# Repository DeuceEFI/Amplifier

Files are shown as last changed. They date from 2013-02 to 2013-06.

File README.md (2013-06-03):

# ST Microelectronics TDA7293V Audio Amplifier

JAG 06/02/2013 2111 EDT (GMT-0400)

### Introduction

This is a high performance audio amplifier board based on the ST Microelectronics TDA7293V 100W Class AB audio amplifier IC.

Please see http://forum.diyefi.org/viewtopic.php?f=37&t=1966 for the most up to date information and links for this project.

### Goals

Core specs:

 * Uses TDA7293 integrated amp IC
 * Single board per chip/channel as small as reasonable with 2 layers without compromising noise performance
 * Simple interface to power and IO signals
 * Combine three together sharing a toroidal and main power filter caps for stereo bookshelfs + optional sub

Method:

 * Use reference schematics and layout as guides in order to minimise time to completion and effort required
 * Linkwitz Riley 24db/octave two way + merge electronic crossover to handle splitting signal for sub and bookshelfs
 * Internal star grounding scheme
 * Add some sophistication and quality by force to the circuit
 * Incorporate ground lift circuit to ensure ground-loop free operation
 * Utilise clip detection feature to drive LED on front panel per channel (20mA, make it obvious) 

Currently we are working on the schematics so no PCB file exists at this time.

### KiCAD modules

Copy the Amplifier.mod file to your KiCAD module directory, typically /usr/share/kicad/modules
 
### Status

This PCB is in active development, please refrain from printing circuit boards and expecting them to work.
This design is untested and should NOT be considered a usable design.

See TODO.md for the latest status of what needs to be done and what has already been done.

I will update this status as work progresses.

### Changes

Please send any changes that you make to the Amplifier back upstream to Andy Goss' copy at https://github.com/DeuceEFI/Amplifier

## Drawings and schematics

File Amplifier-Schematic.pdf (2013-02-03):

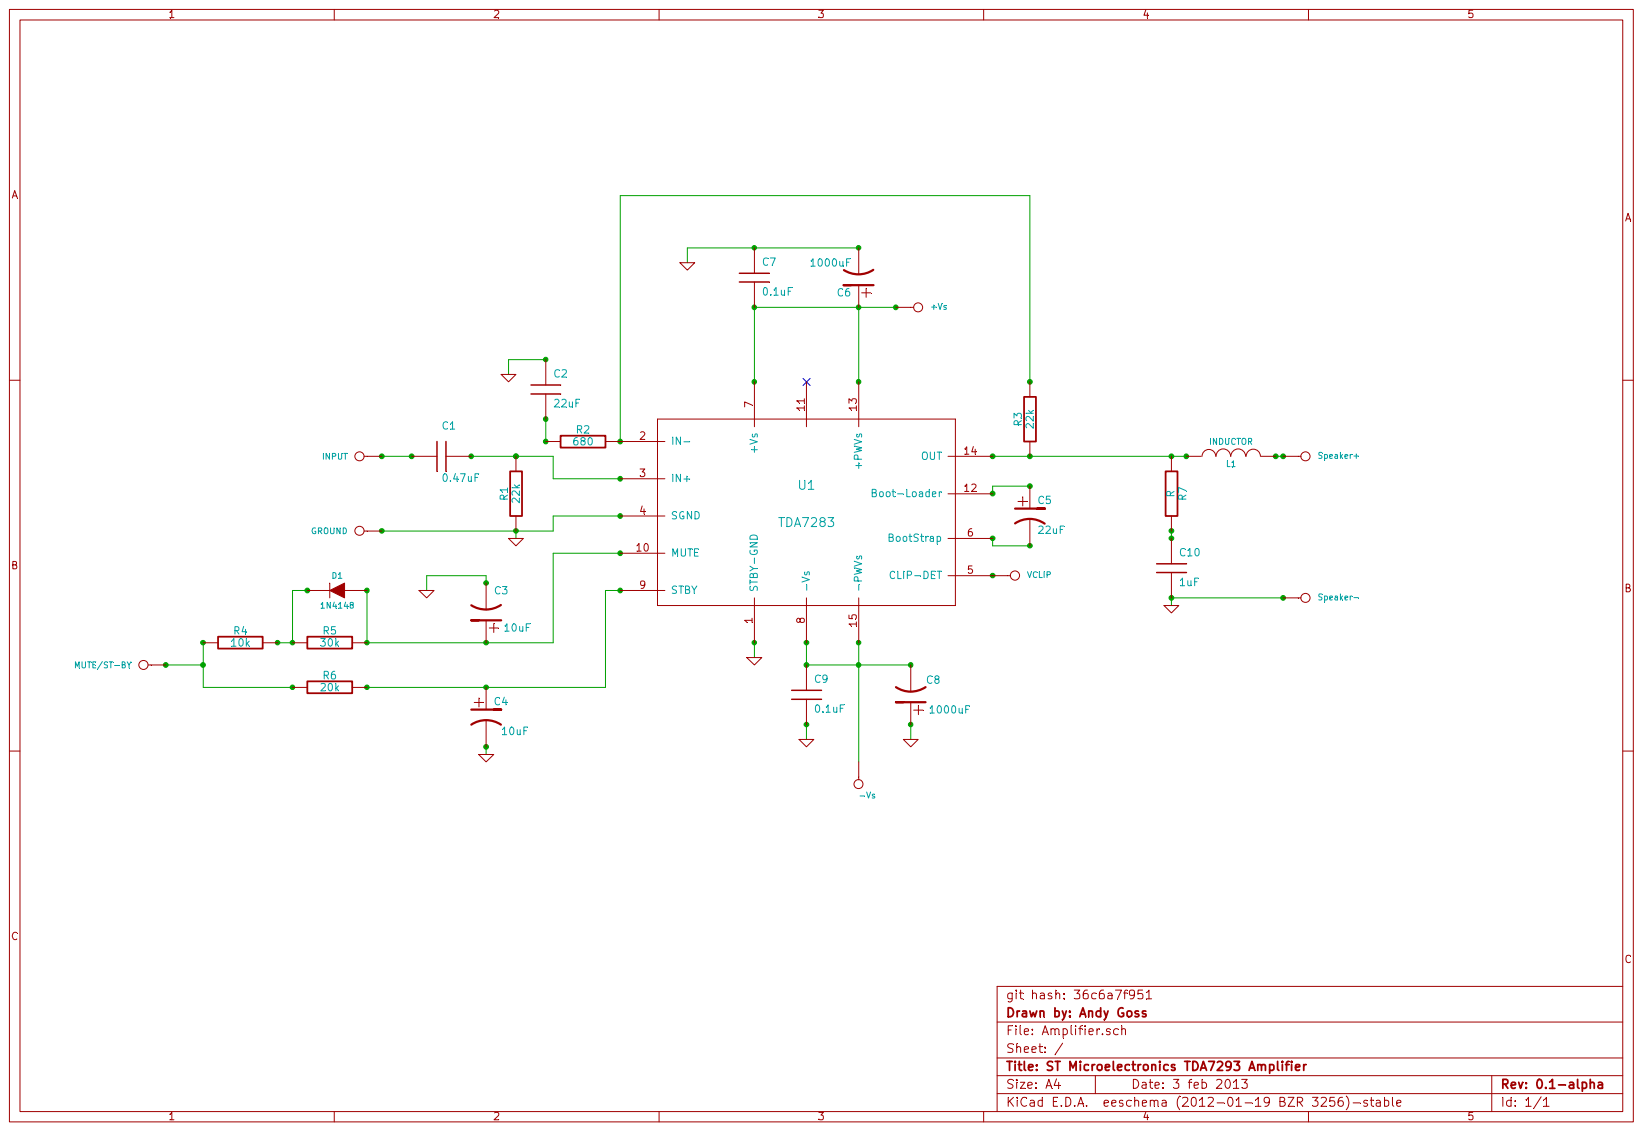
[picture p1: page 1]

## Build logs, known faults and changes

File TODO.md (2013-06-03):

# To Do List

## JAG 06/02/2013 2155 EDT (GMT-0400)

### Tasks to left to do:

* Move the input to the front of the board rather than the side. 
* Move the clip input to the front of the board rather than the side.
* Move the control line to the front of the board rather than the side.
* Move the Mute/Standby to the front of the board rather than the side.
* The traces to/from the capacitors and inductor could be much bigger, tapering at the end for IC connection.
* The ground for the zobel network should be brought out for an independent return to the power supply. That's at the end of C10.
* Review all parts and layout.

----------

### TODO Changes Completed:

* Created Amplifier.mod KiCAD module. - DONE 06/01/2013
* Created Output-Inductor footprint. - DONE 06/01/2013
* Zobel resistors are 5mm diameter with comfortable 21mm lead spacing. - DONE 06/02/2013
* 1000uF decouple are 16.2 OD, 0.8 lead dia, 7.3 lead spacing. - DONE 06/02/2013
* 100uF caps (both types) are 8.2 OD, 0.5 lead dia, 3 lead spacing. - DONE 06/02/2013
* 10uF are tantalum and are 4 OD, 0.5 lead dia, 4.9 lead spacing. - DONE 06/02/2013
* Triple decouple ceramics all have 5 lead spacing and 0.5 lead dia, the thickest one is about 2.5, so the three side by side should give a spacing of 5 total centre to centre from 1uF to 0.01uF. - DONE 06/02/2013
* The MKT 1uF caps are a bit under 4.5mm wide, and 7.2 in the lead spacing direction with 0.5 wire dia, and 5 lead spacing. Note that the input DC block "cap" is three of these in parallel. The remaining one is for the Zobel network. - DONE 06/02/2013
* Resistors are std 1/4 package except for Zobel network resistors. - DONE 06/02/2013
* Diodes are std 1N4007 parts. - DONE 06/02/2013

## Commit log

2013-02-02 Initial commit of this repository.
    [Amplifier.sch]
2013-02-03 Added all components as shown in http://forum.diyefi.org/viewtopic.php?p=30734#p30734
    [Amplifier.sch]
2013-02-03 Added git hash 67c414a9ad to schematic
    [Amplifier.sch]
2013-02-03 Annotated the schematic
    [Amplifier.sch]
2013-02-03 Added license, TODO and README files to the repo.
    [Amplifier.sch]
2013-02-03 Added Amplifier-Schematic.pdf file.
2013-02-04 Made the changes specified at http://forum.diyefi.org/viewtopic.php?p=32437#p32437 Which changed C2 and C5 to 100uF, triple decouple capacitors for both power supply rails, changed input C1 from 0.47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
    [Amplifier.sch]
2013-03-26 Started assigning footprints to components.
2013-06-01 Added Amplifier.mod PCB module file with the Output-Inductor footprint.
2013-06-01 Added Amplifer.brd file with a 143mm x 95mm PCB outline.
    [Amplifier.brd]
2013-06-02 Added ST Microelectronics TDA7293V amplifier KiCAD footprint to the Amplifier.mod file.
2013-06-02 Added PIN footprint to the Amplifier.mod file and placed TDA7293V on the PCB.
    [Amplifier.brd]
2013-06-02 Changed IC part number from TDA7283 to TDA7293. Thanks Fred Cooke for catching that error!
    [Amplifier.brd, Amplifier.sch]
2013-06-02 Output Inductor footprint had pads 1 and 3 but was supposed to have pads 1 and 2, corrected footprint.
2013-06-02 Added R3 and CP_8x13mm footprints to Amplifier.mod file.
    [Amplifier.brd]
2013-06-02 Corrected CP_8mmx13mm footprint and place C2 on the PCB.
    [Amplifier.brd]
2013-06-02 Initial routing of the circuit board.
    [Amplifier.brd, Amplifier.sch]
2013-06-02 Corrected the missing trace from U1 pin 7 to pin 13.
    [Amplifier.brd]
2013-06-02 Made R7 larger, made C1, C15, C16 larger, moved triple decoupling capacitors closer to U1.
    [Amplifier.brd, Amplifier.sch]
2013-06-03 Made mounting holes 2.2mm diameter with 3.5mm pads that are not connected to the ground plane.
    [Amplifier.brd, Amplifier.sch]
2013-06-03 Updated README.md with latest status and to reference the TODO.md file for changes to the PCB.
2013-06-03 Added mounting hole measurements to the PCB file.
    [Amplifier.brd]
2013-06-19 Updated .brd file
    [Amplifier.brd]
